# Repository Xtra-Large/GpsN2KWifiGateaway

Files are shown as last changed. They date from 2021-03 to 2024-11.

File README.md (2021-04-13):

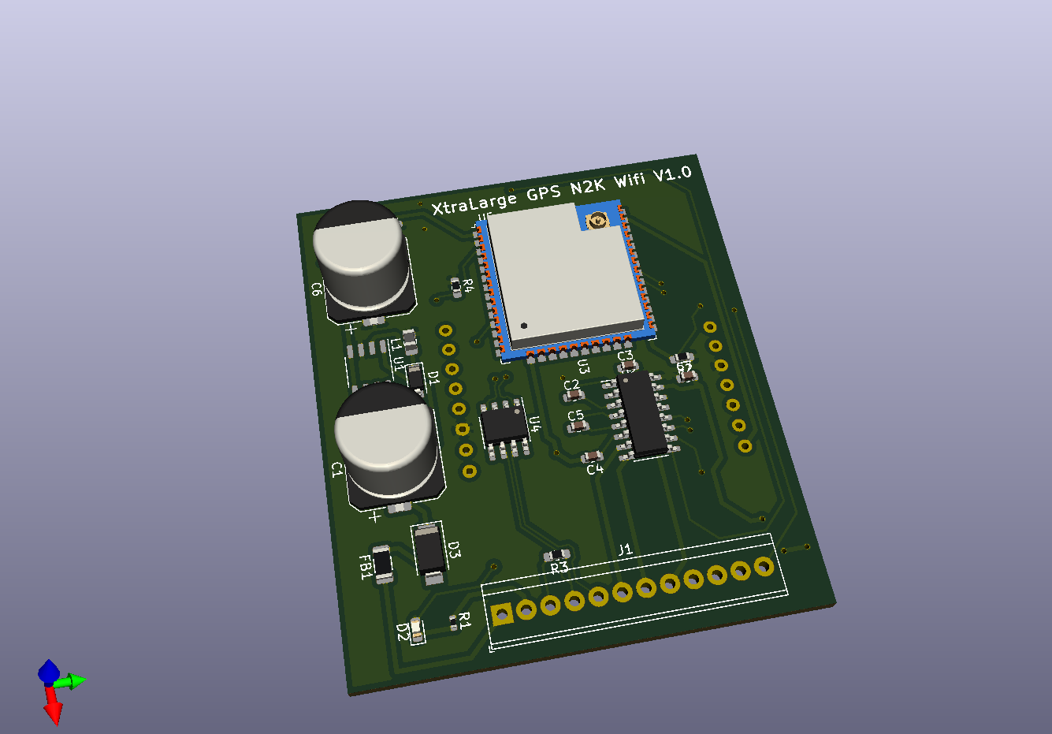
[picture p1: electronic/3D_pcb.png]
Vue 3D


# GpsN2KWifiGateaway

Ce projet est encore en développement, n'hésitez pas à participer!

## Présentation

L'objectif initial de ce projet etait de disposer d'un GPS NMEA 2000 ayant une fréquence de rafraichissement d'au moins 10Hz pour l'intégrer dans notre Archambault A31 (https://epsilon3dsailingteam.fr/).

Il semble que les pilotes automatiques intègrent les données GPS pour effectuer des corrections de trajectoire.

Les GPS Ublox M8N (assez peu couteux) permettent, apèrs configuration, d'obtenir ces taux de rafraichissement en étant mono constellation.
Le nouveelles puces M9N permettent d'obtenir un taux de rafraichissement de 25Hz en exploitant les 4 constellations (GPS, Glonass, Galiléo et Baidoo).

## Projet

Le projet est constitué : 
- Une partie électronique constituée :
  - D'une puce ESP 32 
  - D'un puce GPS M9N, dans la première version nous utilisons une carte Sparkfun (https://www.sparkfun.com/products/15712)
- Un boitier à imprimer en 3D (en cours)
- Le code source du projet

Le code source peut être ouvert avec l'IDE Arduino et le projet électronique avec kiCAD

## Librairies externes utilisées

Le code source utilise ces librairies, sous licence MIT elles aussi :
- Plusieurs librairies de, https://github.com/ttlappalainen : NMEA0183, NMEA2000, NMEA2000_esp32
- https://github.com/ronzeiller/NMEA0183-AIS
- https://github.com/sparkfun/SparkFun_u-blox_GNSS_Arduino_Library

## Fonctions implémentées

Actuellement le projet permet :
- D'injecter sur le réseau NMEA2000 les données de la puce GPS a la fréquence de 20Hz (25Hz possible, a voir l'intérêt)
- Se connecter à un réseau Wifi existant
- Creer un point d'accès Wifi
- Lire les données du réseau NMEA2000, les convertir en MNEA0183 et les router vers :
-- 3 ports série 
-- Wifi en TCP et en UDP

## RoadMap
- Page Web de configuration visualisation
  - Ajout du serveur de configuration Wifi pour configuration sur un routeur externe
  - Ajout de fonction AJAX/JSON pour rechargement de la page de statut
  - Mise en une seule page pour intégrer la fonction de MAJ du firmware
  - Ajout d'option pour activer certaines redirections vers les ports et le reseau (a stocker en NVS)
  - Mise en page et logo
  - Configuration des ports de sortie serie : Msg NMEA, vitesse, activation...
  - Configuration du SSID externe + PWD

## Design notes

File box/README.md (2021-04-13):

# GpsN2KWifiGateaway Box

Ce projet est encore en développement, n'hésitez pas à participer!

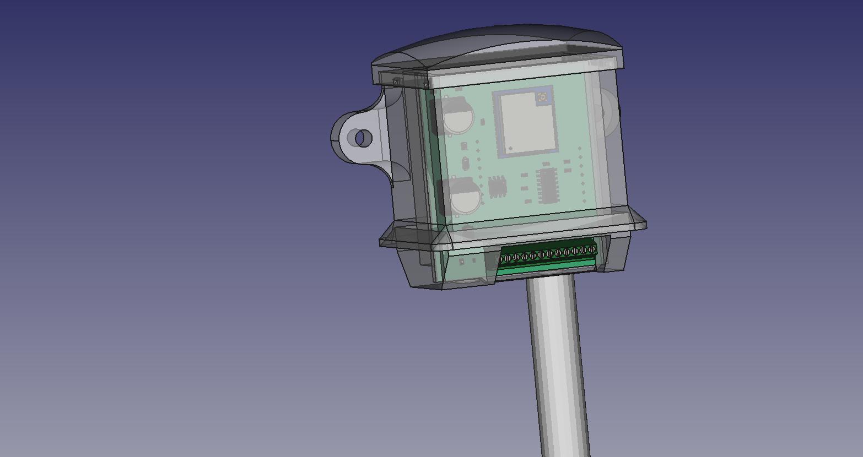
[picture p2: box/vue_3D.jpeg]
Vue 3D


Ce boitier permet l'intégration et la fixation du GPS dans le bateau.

Il n'est pas étanche, mais il est conçu de telle manière que l'eau ne rentre pas dedans, et que la condensation puisse s'évacuer.

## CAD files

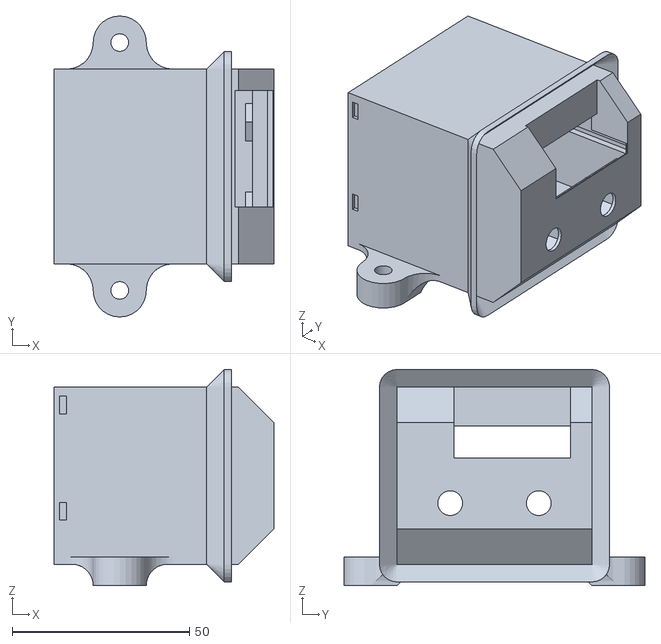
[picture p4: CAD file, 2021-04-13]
box/Boitier (Meshed).stl
62.0 x 85.0 x 61.0

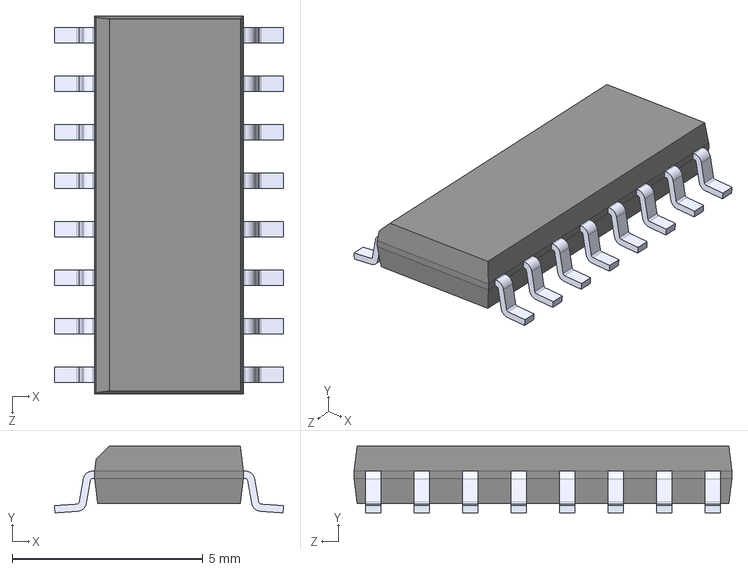
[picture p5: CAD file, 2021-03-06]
electronic/Composants/MAX3232CDR.step
6.00 x 1.75 x 9.90 mm

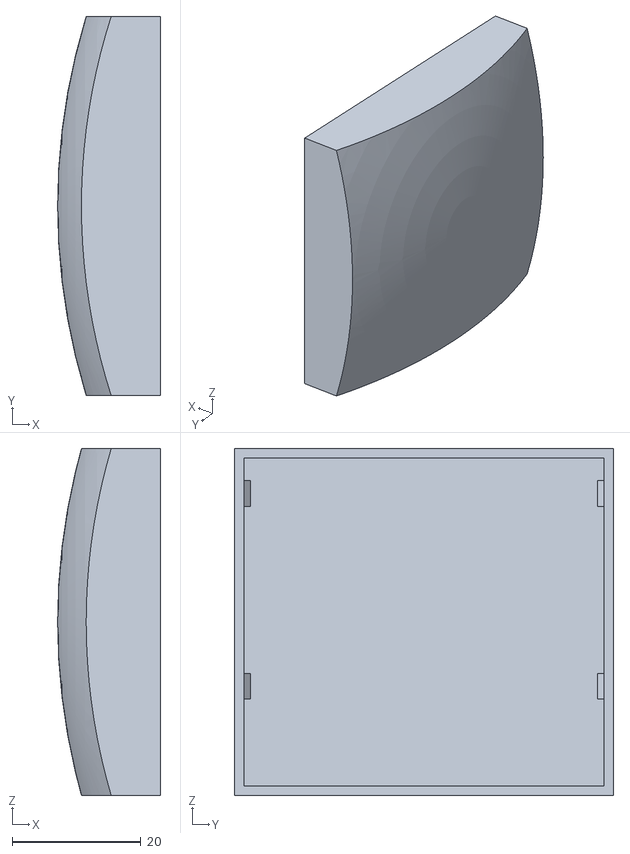
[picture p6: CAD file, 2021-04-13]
box/Couvercle (Meshed).stl
16.0 x 59.0 x 54.0

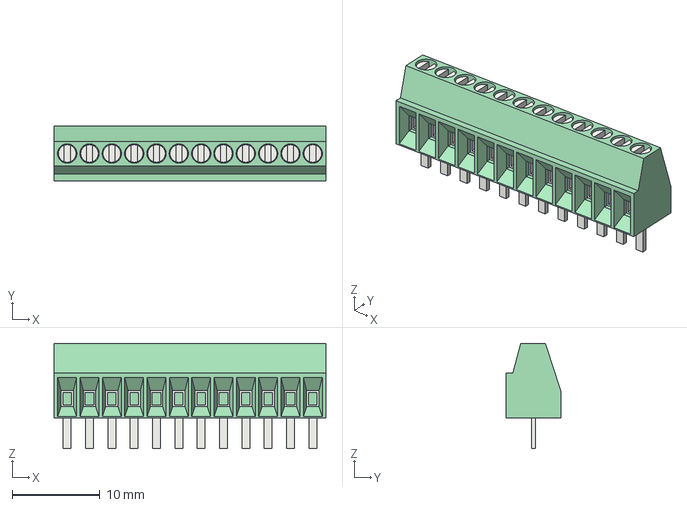
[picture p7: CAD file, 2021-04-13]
box/TerminalBlock_Phoenix_MPT-0,5-12-2.54_1x12_P2.54mm_Horizontal.step
30.9 x 6.20 x 12.0 mm

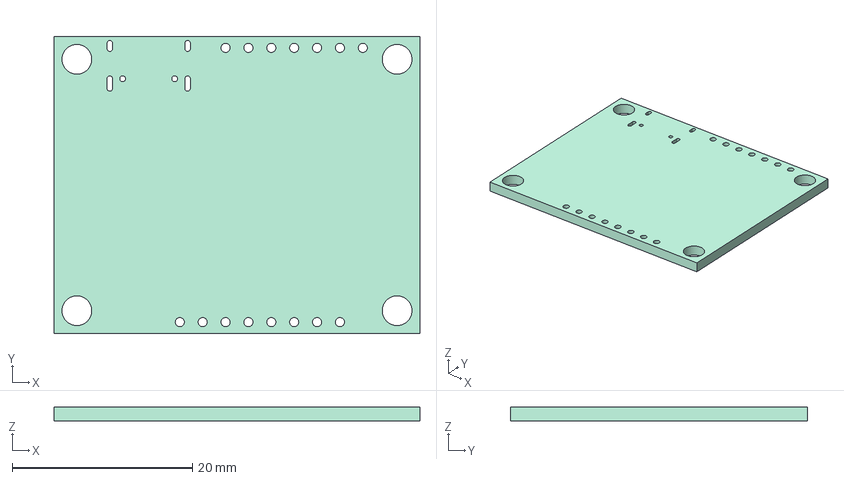
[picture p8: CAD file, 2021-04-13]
box/SparkFun GPS NEO_M9N_uFL1-SparkFun GPS NEO_M9N_uFL.step
40.6 x 33.0 x 1.60 mm

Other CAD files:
box/boitier.FCStd

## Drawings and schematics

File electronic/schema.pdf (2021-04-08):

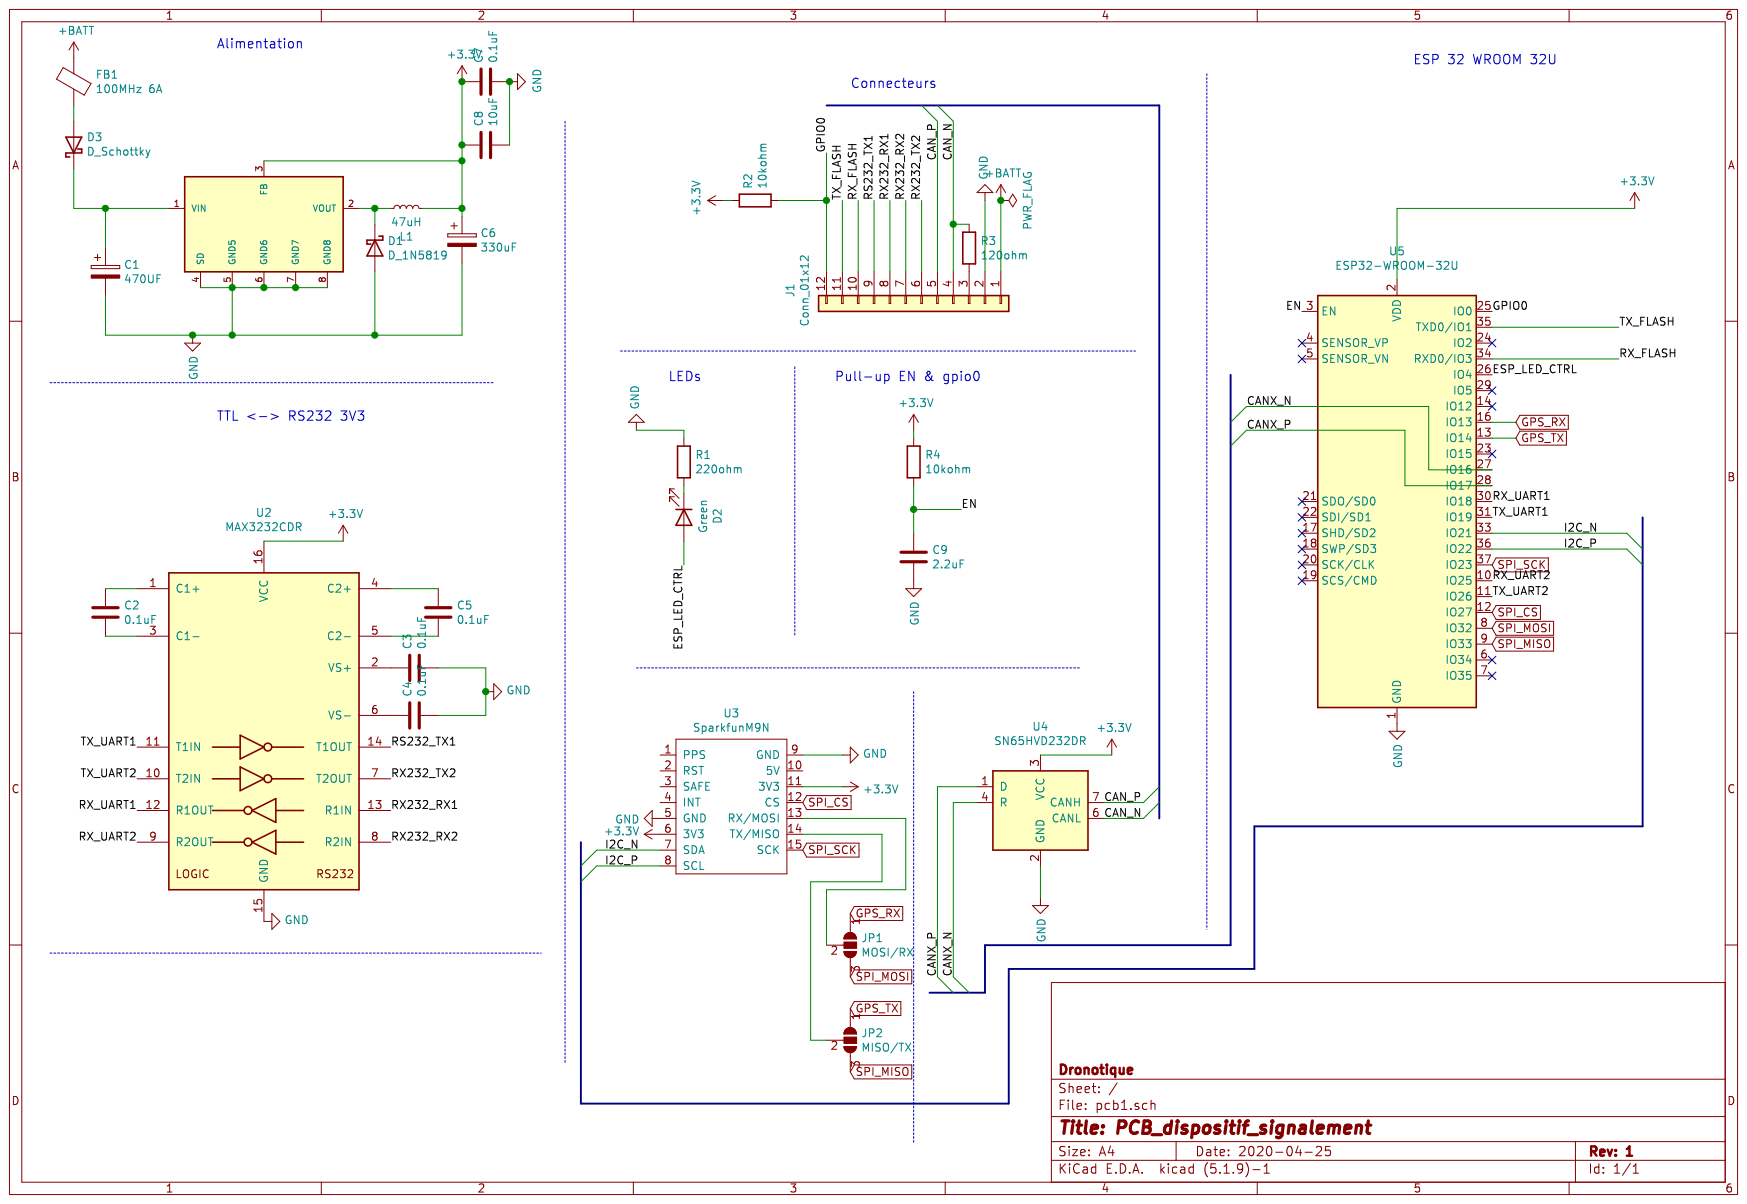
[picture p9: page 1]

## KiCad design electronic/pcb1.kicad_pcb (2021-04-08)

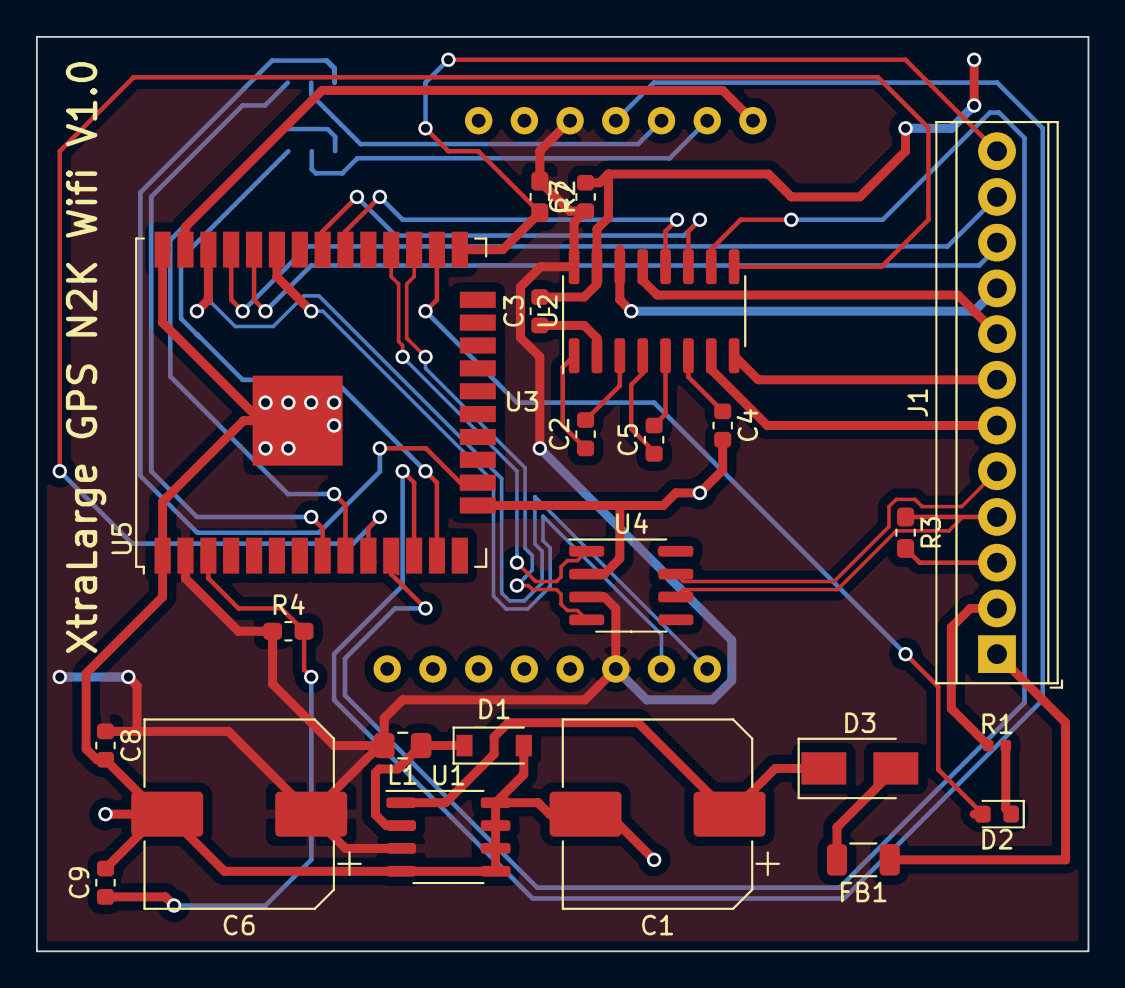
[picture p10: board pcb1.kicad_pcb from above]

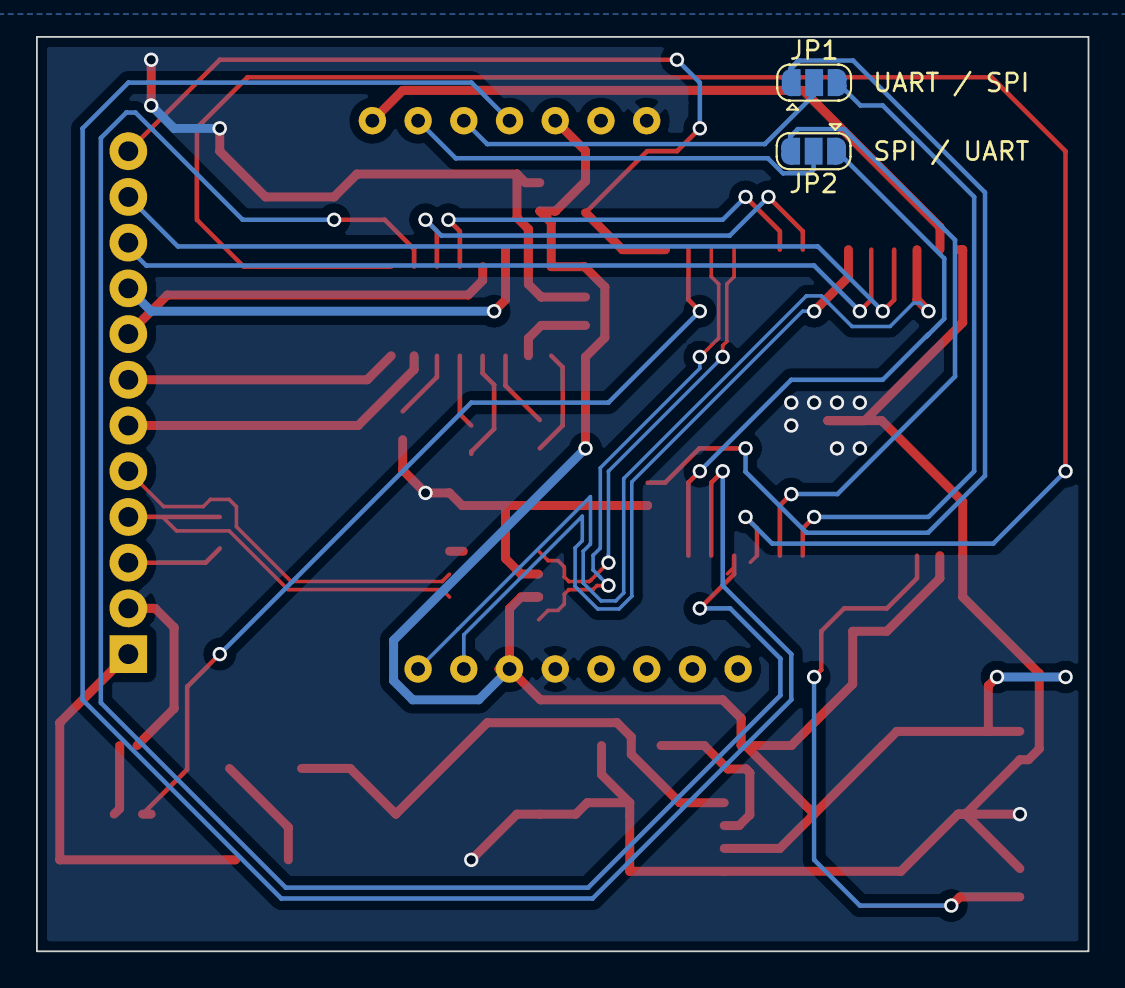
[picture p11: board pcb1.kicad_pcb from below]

Board: 2 copper layers, 58.4 x 50.8 mm, 26 parts (2 on the bottom side), 41 nets.

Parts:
C1: 470UF; CP_Elec_10x10
C2, C3, C4, C5, C7: 0.1uF; C_0603_1608Metric
C6: 330uF; CP_Elec_10x10
C8: 10uF; C_0603_1608Metric
C9: 2.2uF; C_0603_1608Metric
D1: D_1N5819; D_SOD-123
D2: Green; LED_0603_1608Metric
D3: D_Schottky; D_SMA
FB1: 100MHz 6A; R_1206_3216Metric
J1: Conn_01x12; TerminalBlock_TE_1-282834-2_1x12_P2.54mm_Horizontal
JP1: MOSI/RX; SolderJumper-3_P1.3mm_Open_RoundedPad1.0x1.5mm
JP2: MISO/TX; SolderJumper-3_P1.3mm_Open_RoundedPad1.0x1.5mm
L1: 47uH; L_0805_2012Metric_Pad1.15x1.40mm_HandSolder
R1: 220ohm; R_0402_1005Metric
R2, R4: 10kohm; R_0603_1608Metric_Pad1.05x0.95mm_HandSolder
R3: 120ohm; R_0603_1608Metric_Pad1.05x0.95mm_HandSolder
U1: XLSEMI XL1509-3.3E1; SOP-8_3.9x4.9mm_P1.27mm
U2: MAX3232CDR; SOIC-16_3.9x9.9mm_P1.27mm
U3: SparkfunM9N; AdafruitGPSM9N
U4: SN65HVD232DR; SOIC-8_3.9x4.9mm_P1.27mm
U5: ESP32-WROOM-32U

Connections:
+3V3: C6.1, C7.1, C8.1, L1.2, R2.1, R4.1, U1.3, U2.16, U3.6, U3.11, U4.3, U5.2
+BATT: FB1.1, J1.1
/CANX_N: U4.4, U5.27
/CANX_P: U4.1, U5.28
/CAN_N: J1.4, R3.1, U4.6
/CAN_P: J1.5, U4.7
/EN: C9.1, R4.2, U5.3
/ESP_LED_CTRL: D2.2, U5.26
/GPIO0: J1.12, R2.2, U5.25
/I2C_N: U3.7, U5.33
/I2C_P: U3.8, U5.36
/RS232_TX1: J1.9, U2.14
/RX232_RX1: J1.8, U2.13
/RX232_RX2: J1.7, U2.8
/RX232_TX2: J1.6, U2.7
/RX_FLASH: J1.10, U5.34
/RX_UART1: U2.12, U5.30
/RX_UART2: U2.9, U5.10
/TX_FLASH: J1.11, U5.35
/TX_UART1: U2.11, U5.31
/TX_UART2: U2.10, U5.11
GND: C1.2, C3.2, C4.2, C6.2, C7.2, C8.2, C9.2, D1.2, J1.2, R1.1, U1.4, U1.5, U1.6, U1.7, U1.8, U2.15, U3.5, U3.9, U4.2, U5.1, U5.15, U5.38, U5.39
GPS_RX: JP1.1, U5.16
GPS_TX: JP2.1, U5.13
unnamed: C1.1, D3.1, U1.1
unnamed: C2.1, U2.1
unnamed: C2.2, U2.3
unnamed: C3.1, U2.2
unnamed: C4.1, U2.6
unnamed: C5.1, U2.4
unnamed: C5.2, U2.5
unnamed: D1.1, L1.1, U1.2
unnamed: D2.1, R1.2
unnamed: D3.2, FB1.2
unnamed: J1.3, R3.2
unnamed: JP1.2, U3.13
unnamed: JP2.2, U3.14
SPI_CS: U3.12, U5.12
SPI_MISO: JP2.3, U5.9
SPI_MOSI: JP1.3, U5.8
SPI_SCK: U3.15, U5.37

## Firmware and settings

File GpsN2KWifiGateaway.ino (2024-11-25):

/*
Copyright (c) 2021-2025 Aurelien TRICAULT - XtraLarge
Permission is hereby granted, free of charge, to any person obtaining a copy of
this software and associated documentation files (the "Software"), to deal in
the Software without restriction, including without limitation the rights to use,
copy, modify, merge, publish, distribute, sublicense, and/or sell copies of the
Software, and to permit persons to whom the Software is furnished to do so,
subject to the following conditions:
The above copyright notice and this permission notice shall be included in all
copies or substantial portions of the Software.
THE SOFTWARE IS PROVIDED "AS IS", WITHOUT WARRANTY OF ANY KIND, EXPRESS OR IMPLIED,
INCLUDING BUT NOT LIMITED TO THE WARRANTIES OF MERCHANTABILITY, FITNESS FOR A
PARTICULAR PURPOSE AND NONINFRINGEMENT. IN NO EVENT SHALL THE AUTHORS OR COPYRIGHT
HOLDERS BE LIABLE FOR ANY CLAIM, DAMAGES OR OTHER LIABILITY, WHETHER IN AN ACTION OF
CONTRACT, TORT OR OTHERWISE, ARISING FROM, OUT OF OR IN CONNECTION WITH THE SOFTWARE
OR THE USE OR OTHER DEALINGS IN THE SOFTWARE.
*/


/**Ce programme utilise les librairies suivantes :
 * https://github.com/ttlappalainen/NMEA0183
 * https://github.com/ttlappalainen/NMEA2000
 * https://github.com/ttlappalainen/NMEA2000_esp32
 * https://github.com/ronzeiller/NMEA0183-AIS
 * https://github.com/sparkfun/SparkFun_u-blox_GNSS_Arduino_Library
 * 
 * 
 * Il faut aussi installer manuellement la librairie BlinkControl, celle fournie par les IDE Arduino n'etant plus MAJ
 * https://github.com/Xtra-Large/BlinkControl
 * 
 */

/**
 * TODO
 *  - Ajout UDP sur IP locale?
 *  - Ajout du serveur de configuration Wifi pour configuration sur un routeur externe
 *  - TCP NMEA2K (voir si intéret)
 *  - UDP NMEA2K (voir si intéret)
 *  - Ajout de fonction AJAX/JSON pour rechargement de la page de statut
 *    -> Mise en une seule page pour intégrer la fonction de MAJ du firmware
 *    -> Ajout d'option pour activer certaines redirections vers les ports et le reseau (a stocker en NVS)
 *    -> Mise en page et logo
 *    -> Configuration des ports de sortie serie : Msg NMEA, vitesse, activation...
 *    -> Configuration du SSID externe + PWD
 *  - TCP Broadcast NMEA2K (voir si intéret)
 *  - TCP Broadcast NMEA0183
 *  
 *  20210213 
 *    - ADD HOSTNAME + services DNS
 *    - Sortie NMEA0183 sur les 3 ports serie (pour ajout éventuel d'un pilote sur ce port)
 *    - Ajout port serie 2
 *    - UDP NMEA0183 broadcast
 *    - TCP NMEA1083

 *  20241125
 *    - MAJ des librairies pour compilation
 */


#pragma once
/*
  * Module de conversion GPS Ublox (M8N) vers NMEA 2000 à 10Hz
  * Copyright Dronotique - Aurélien TRICAULT
 */

extern "C" {
#include "esp_wifi.h"
#include "driver/uart.h"
}
 
#define DEBUG_ON false

#define VERSION 0.12
#define VERSION_STR "0.12"
#include <cstdint>
#include <Arduino.h>
#include <WiFi.h>
#include <WebServer.h>
#include <BlinkControl.h>
//OTA
#include <WiFiClient.h>
#include <ESPmDNS.h>
#include <Update.h>

//Manipulation des dates/times
#include <TimeLib.h>

//Stockage de l'adresse sur le bus N2K
#include <Preferences.h>
int NodeAddress;  // To store last Node Address
Preferences preferences;             // Nonvolatile storage on ESP32 - To store LastDeviceAddress
bool updateEnCours = false;

#include "configuration.h"

#include <Wire.h> //Needed for I2C to GPS


//gestion des pins
#define RX2_PIN GPIO_NUM_25
#define TX2_PIN GPIO_NUM_26
//#define RX1_PIN GPIO_NUM_9 //Non utilisable
//#define TX1_PIN GPIO_NUM_10 //Non utilisable
#define RX1_PIN GPIO_NUM_18
#define TX1_PIN GPIO_NUM_19
#define RX0_PIN GPIO_NUM_3
#define TX0_PIN GPIO_NUM_1
#define I2C_SDA GPIO_NUM_21
#define I2C_SCL GPIO_NUM_22
//#define ESP32_CAN_TX_PIN GPIO_NUM_16
//#define ESP32_CAN_RX_PIN GPIO_NUM_4
//#define ESP32_CAN_TX_PIN GPIO_NUM_5
//#define ESP32_CAN_RX_PIN GPIO_NUM_4
#define ESP32_CAN_TX_PIN GPIO_NUM_17
#define ESP32_CAN_RX_PIN GPIO_NUM_16
#define SPI_SCK GPIO_NUM_23
#define SPI_CS GPIO_NUM_27
#define SPI_MOSI GPIO_NUM_32
#define SPI_MISO GPIO_NUM_33

//#include <HardwareSerial.h>
//HardwareSerial MySerial1(1);
#define GNSS_ON_SERIAL false
#define DEFAULT_BAUD_RATE 115200
#define BAUD_RATE_SIZE 5
int baudsRates[] = {38400, 115200, 9600, 57600, 4800};



//GPS
//#include <SparkFun_Ublox_Arduino_Library.h>
#include <SparkFun_u-blox_GNSS_Arduino_Library.h>
#define NUM_SAT_MIN 5
#define GPS_HDOP_MIN 2.5
#define defaultMaxWait 10000 //Max wait for GPS Ublox ... Augmenter car bug sinon
SFE_UBLOX_GNSS myGNSS;
#define MAX_GPS_FREQUENCY 25

//NMEA 2000
#define N2K_FRAME_BUFFER_SIZE 250
#define N2K_FRAME_RECEIVE_BUFFER_SIZE 100


//#define NMEA2000_FRAME_ERROR_DEBUG
//#define NMEA2000_FRAME_IN_DEBUG
//#define NMEA2000_FRAME_OUT_DEBUG
//#define NMEA2000_MSG_DEBUG
//#define NMEA2000_BUF_DEBUG
//#define NMEA2000_DEBUG

#include <NMEA2000_CAN.h>
#include <N2kMessages.h>

// List here messages your device will transmit.
// Set the information for other bus devices, which messages we support
const unsigned long TransmitMessages[] PROGMEM = {129029L,129026L,129025L,0};
const unsigned long ReceiveMessages[] PROGMEM = {/*126992L,*/ // System time
      127250L, // Heading
      127258L, // Magnetic variation
      128259UL,// Boat speed
      128267UL,// Depth
      129025UL,// Position
      129026L, // COG and SOG
      129029L, // GNSS
      129025L, // LAT + LON RAPID
      130306L, // Wind
      128275UL,// Log
      127245UL,// Rudder
      129038L, //AIS Classe A
      129039L, //AIS Classe B
      12979UL, //AIS Classe A static
      129809L, //AIS Classe B static
      129810L, //AIS Classe B static
      0
    };

#define RapidDataUpdatePeriod 50 //20Hz //In millisec - Some strange periot to cause Slow and rapid to run unsync.
#define SlowDataUpdatePeriod 500 //2Hz //In millisec - Some strange periot to cause Slow and rapid to run unsync.
#define MiscDataUpdatePeriod 5000 //0.2Hz //In millisec - Some strange periot to cause Slow and rapid to run unsync.
unsigned long RapidDataUpdated=0;
unsigned long SlowDataUpdated=0;
unsigned long MiscDataUpdated=0;

//COnversion en NMEA0183
#include "N2kDataToNMEA0183.h"
#include "List.h"
#include "BoardSerialNumber.h"
#include "BoatData.h"
#include <WiFiUdp.h>
#define SEND_SEA_SMART true
#if SEND_SEA_SMART 
  #include "Seasmart.h"
#endif

using namespace std;

//Gestion de la led
/*4 mode pour la led
 * Eteinte = Module non alimenté
 * Fixe = Initialisation en cours
 * Clignotement lent = Acquisition GPS en cours
 * Clignotement rapide = Module prêt
 */
#define PIN_LED 12 //16
BlinkControl led(PIN_LED);
int blinkState = 0; //0 = ON, 1 = 1hZ, 2=3hz

//GPS 
#define NUM_SAT_MIN 5 //Nombre de satelitte mini pour considérer la position comme valide
#define GPS_HDOP_MIN 4 //HDOP mini pour considérer la position comme valide
#define HZ_TO_READ_GPS 10 //Frequence de la lecture de la position GPS
long lastTimeReadGPS; //Dernière lectuer du GPS

bool gpsInitialized = false;

long n2kMsgId = 0;

tBoatData boatData;
bool gpsPositionUpdated = false;
bool gpsCogSogUpdated = false;

bool initiatlisationCompleted = false;

//SSID et PWD
#define HOSTNAME "GPS20HZN2K"
#define WIFI_SSID "GPS20HZN2K"
#define WIFI_PWD "xtralarge"
#define WIFI_CHANNEL 6
String mySsid;
String myPwd;

//Connexion au Wifi du bateau => TODO Passer les valeur en NVS et les rendre editable via l'interface Web
const char *wifi_network_ssid = "XXXXXXXXXXXXXXXX";
const char *wifi_network_password = "XXXXXXXXXXXXXXXXXXXXXXX";

//Server Web OTA et webApp
// Set web server port number to 80
#define WEBSERVER_PORT 80
WebServer server(WEBSERVER_PORT);

//Web Server NMEA0183 TCP et UDP
tN2kDataToNMEA0183 tN2kDataToNMEA0183(&NMEA2000, 0);
#define MAX_TCP_CLIENT_NMEA0183 10
#define WIFISERVER_NMEA0183_PORT 2947
#define UDP_NMEA0183_PORT 2948
WiFiServer serverNMEA0183(WIFISERVER_NMEA0183_PORT, MAX_TCP_CLIENT_NMEA0183); //10 clients max
using tWiFiClientPtr = std::shared_ptr<WiFiClient>;
LinkedList<tWiFiClientPtr> clientsNMEA0183;
WiFiUDP udpNmea0183;

#define MAX_TCP_CLIENT_NMEA2K 10
#define WIFISERVER_NMEA2K_PORT 2948
#define UDP_NMEA2K_PORT 2948
WiFiServer serverNMEA2K(WIFISERVER_NMEA0183_PORT, MAX_TCP_CLIENT_NMEA0183); //10 clients max
using tWiFiClientPtr = std::shared_ptr<WiFiClient>;
LinkedList<tWiFiClientPtr> clientsNMEAN2K;
//WiFiUDP udpNmea2K;

IPAddress broadCastIPAddress;
IPAddress broadCastIPAddressStation;

#define TIME_DEBUG_ALIVE  300000 //Au bout de 5 minutes on eteind toutes les fonctionnalités de debug (Serial1 et Wifi + OTA)
String gpsCnxMode = "AUCUN GPS";

int printLogs(const char *fmt, va_list args) {
  Serial.print(fmt);
}

void setup() {
  esp_log_set_vprintf(printLogs);
  
  Serial.begin(DEFAULT_BAUD_RATE);
  //Serial1.begin(DEFAULT_BAUD_RATE, SERIAL_8N1, RX1_PIN, TX1_PIN, true, 11000UL);  // Passing 0 for baudrate to detect it, the last parameter is a timeout in ms
  Serial1.begin(DEFAULT_BAUD_RATE, SERIAL_8N1, RX1_PIN, TX1_PIN);
  Serial2.begin(DEFAULT_BAUD_RATE, SERIAL_8N1, RX2_PIN, TX2_PIN);
  //Serial1.begin(DEFAULT_BAUD_RATE);
  Serial.println("////////////////////////////////////////////////////////");
  Serial.print("GPS 20 Hz NMEA 2000/0183 - Version : ");
  Serial.print(VERSION);
  uint32_t id = GetBoardSerialNumber();
  Serial.print(" SN : ");
  Serial.println(id);                               
  Serial.println("////////////////////////////////////////////////////////");
  
  led.begin();
  led.on();

  //COnfiguration du reseau et serveur WIFI
  mySsid = String(WIFI_SSID); 
  char ssid_c[mySsid.length()];
  mySsid.toCharArray(ssid_c, mySsid.length());
  WiFi.config(INADDR_NONE, INADDR_NONE, INADDR_NONE, INADDR_NONE);
  WiFi.setHostname(HOSTNAME);
  WiFi.mode(WIFI_MODE_APSTA);
  WiFi.softAP(ssid_c, WIFI_PWD, WIFI_CHANNEL, false, 4);
  //Connexion au routeur Wifi
  WiFi.begin(wifi_network_ssid, wifi_network_password);

  broadCastIPAddressStation = WiFi.localIP(); // find my local IP address
  broadCastIPAddress = WiFi.softAPIP();
  broadCastIPAddressStation[3] = 255;
  broadCastIPAddress[3] = 255;         // Set last octet to 255 for Class C broadcast address of this subnet

  String ipAdrrAP = String(broadCastIPAddress[0]) + "." + String(broadCastIPAddress[1]) + "." + String(broadCastIPAddress[2]) + "." + String(broadCastIPAddress[3]);
  String ipAdrrStation = String(broadCastIPAddressStation[0]) + "." + String(broadCastIPAddressStation[1]) + "." + String(broadCastIPAddressStation[2]) + "." + String(broadCastIPAddressStation[3]);
  MDNS.begin(HOSTNAME);
  MDNS.addService("_nmea","_udp",UDP_NMEA0183_PORT);
  MDNS.addServiceTxt("_nmea","_udp","Host",HOSTNAME);
  MDNS.addServiceTxt("_nmea","_udp","IP", ipAdrrAP);
  MDNS.addService("_nmea","_tcp",UDP_NMEA0183_PORT);
  MDNS.addServiceTxt("_nmea","_tcp","Host",HOSTNAME);
  MDNS.addServiceTxt("_nmea","_tcp","IP", ipAdrrAP);
   
  configureWebServer();

#if DEBUG_ON
  Serial.print("UDP Adresse : ");
  Serial.print(broadCastIPAddress[0]);
  Serial.print(".");
  Serial.print(broadCastIPAddress[1]);
  Serial.print(".");
  Serial.print(broadCastIPAddress[2]);
  Serial.print(".");
  Serial.println(broadCastIPAddress[3]);
#endif
  vTaskDelay(1000/portTICK_PERIOD_MS);
#if DEBUG_ON
    myGNSS.enableDebugging(Serial, false);
#endif

  //Trying UART
  //Connexion au GPS par le port serie
  //Serial.begin(baudsRates[0], SERIAL_8N1, -1, -1);
#if GNSS_ON_SERIAL   
  int i=0;
  for(i; i < BAUD_RATE_SIZE; i++){
#if DEBUG_ON
    Serial.print("Trying on UART port with baudrate : ");
    Serial.println(baudsRates[i]);
#endif
    Serial1.updateBaudRate(baudsRates[i]);
    vTaskDelay(100/portTICK_PERIOD_MS);
    
    gpsInitialized = myGNSS.begin(Serial1);
    if (gpsInitialized){
      break;
    }
    //A t'on trouvé 
    if (gpsInitialized){
      gpsCnxMode = "UART";
#if DEBUG_ON
      Serial.print("GPS initialisé a une vitesse de ");
      Serial.print(baudsRates[i]);
      Serial.println(" BAUD");
#endif
      delay(100);
      if(i != 0){ //On n'est pas sur la vitesse par defaut, on change ca
#if DEBUG_ON
        Serial.print("Changement du BAUD rate pour ");
        Serial.println(baudsRates[0]);
#endif
        //myGNSS.setSerial1Rate(baudsRates[0]);
        delay(100);
      }
    }else{
      Serial.println("Aucun GPS trouvé sur le port UART");
    }
  }
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
void loop() {
  if(updateEnCours){
    vTaskDelay(10000/portTICK_PERIOD_MS);
  }
  //Reception des trames NMEA2000 et envoi NMEA0183
  CheckConnectionsNMEA0183();
  //Taches de gestions globales
  server.handleClient();
  led.loop();

  if (isPositionValide()) {
      //Position GPS valide 
    if(blinkState != 2){
      led.blink3();
      blinkState = 2;
    } 
  }else{
    //Attente position GPS
    if(blinkState != 1){
      led.blink1();  
      blinkState = 1;
    }  
  }
  vTaskDelay(10/portTICK_PERIOD_MS);
}



//###################################################################################
//Serveur Web
//###################################################################################
void configureWebServer(){
  server.on("/", home_page);
  server.on("/update", update_page);
  
  /*handling uploading firmware file */
  server.on("/update_go", HTTP_POST, update_go_page, update_HandleFirware);
  server.begin();
}

void home_page(){
  
  String homePage = WEB_HOME_PAGE;
  homePage.replace("[VERSION]", String(VERSION));
  homePage.replace("[ID_DISPOSITIF]", String(GetBoardSerialNumber()));
  homePage.replace("[PROTOCOLE_MODE]", gpsCnxMode);
  
  if(gpsInitialized){
    //homePage.replace("[FIX_GPS]", (_droneSignal.isPositionFixed() ? "OUI" : "En attente"));
    homePage.replace("[NB_SAT]", String(boatData.nbSat));
    //homePage.replace("[HDOP]", String(_droneSignal.getGpsHdop()));
    //String curLat = DD_DDDDDtoDDMMSS(abs(_droneSignal.getLat())/100000.0);
    String curLat = String(abs((double)boatData.Latitude/10000000.0));
    curLat.replace("°", "&deg;");
    homePage.replace("[LAT]", (boatData.Latitude>=0 ? "N" : "S") + curLat);
    //String curLng = DD_DDDDDtoDDMMSS(abs(_droneSignal.getLon())/100000.0);
    String curLng = String(abs((double)boatData.Longitude/10000000.0));
    curLng.replace("°", "&deg;");
    homePage.replace("[LON]", (boatData.Longitude>=0 ? "E" : "O") + curLng);
    homePage.replace("[Alt]", String((double) ((double)boatData.Altitude/1000.0f)));
    homePage.replace("[SPEED]", String((double) ((double)boatData.SOG/1000.0)));
    homePage.replace("[ROUTE]", String((double) (((double)boatData.COG/100000.0)* M_PI /180.0)));
  }else{
    homePage.replace("[FIX_GPS]", "GPS Non initialisé");
  }

  server.send(200, "text/html", homePage); 
}

void update_page(){
  server.send(200, "text/html", WEB_UPDATE_PAGE); 
}

void update_go_page(){
  server.sendHeader("Connection", "close");
  server.send(200, "text/plain", (Update.hasError()) ? "FAIL" : "OK");
  ESP.restart();
}

void update_HandleFirware(){
  HTTPUpload& upload = server.upload();
  if (upload.status == UPLOAD_FILE_START) {
    Serial.printf("Update: %s\n", upload.filename.c_str());
    updateEnCours = true;
    if (!Update.begin(UPDATE_SIZE_UNKNOWN)) { //start with max available size
      updateEnCours = false;
      Update.printError(Serial1);
    }
  } else if (upload.status == UPLOAD_FILE_WRITE) {
    /* flashing firmware to ESP*/
    if (Update.write(upload.buf, upload.currentSize) != upload.currentSize) {
      updateEnCours = false;
      Update.printError(Serial1);
    }
  } else if (upload.status == UPLOAD_FILE_END) {
    if (Update.end(true)) { //true to set the size to the current progress
      Serial.printf("Update Success: %u\nRebooting...\n", upload.totalSize);
    } else {
      updateEnCours = false;
      Update.printError(Serial1);
    }
  }
}


//###################################################################################
//GPS
//###################################################################################

bool isPositionValide(){
  //return ( _droneSignal.isPositionFixed() && _droneSignal.getSatNumber() >= NUM_SAT_MIN && _droneSignal.getGpsHdop() <= GPS_HDOP_MIN);
  return true;
}

String DD_DDDDDtoDDMMSS( double DD_DDDDD)
{    
 int DD=(int)DD_DDDDD;
 int MM=(int)((DD_DDDDD - DD)*60);
 int SS=(int)((DD_DDDDD - DD)*60-MM)*60;
 return String(DD) + "°" + String(MM) + "'" + String(SS);
}

//###################################################################################
//NMEA2000
//###################################################################################
bool IsTimeToUpdate(unsigned long NextUpdate) {
  return (NextUpdate<millis());
}

unsigned long InitNextUpdate(unsigned long Period, unsigned long Offset=0) {
  return millis()+Period+Offset;
}

unsigned long InitNextUpdate(unsigned long Period) {
  return InitNextUpdate(Period, 0);
}

void SetNextUpdate(unsigned long &NextUpdate, unsigned long Period) {
  while ( NextUpdate<millis() ) NextUpdate+=Period;
}


//###################################################################################
//SEASMART
//###################################################################################
#define MAX_NMEA2000_MESSAGE_SEASMART_SIZE 500
#define MAX_NMEA2000_MESSAGE_SIZE 82
//*****************************************************************************
//NMEA 2000 message handler
void HandleNMEA2000Msg(const tN2kMsg &N2kMsg) {
  char buf[MAX_NMEA2000_MESSAGE_SEASMART_SIZE];
#if SEND_SEA_SMART
    if (N2kToSeasmart(N2kMsg, millis(), buf, MAX_NMEA2000_MESSAGE_SEASMART_SIZE) == 0 ){  
      SendBufToClients(buf);
    }
#endif

//TODO send UDP and TCP N2K message 
  /*char bufN2k[MAX_NMEA2000_MESSAGE_SIZE]; 
  int n2kMsgLenght = 0;
  N2kMsg.GetBuf(bufN2k, MAX_NMEA2000_MESSAGE_SIZE, n2kMsgLenght);
  Serial.println("Sending UDP NMEA2K message");
  udpNmea2K.beginPacket(broadCastIPAddress, UDP_NMEA2K_PORT);  // Send to UDP
  udpNmea2K.write((byte*)bufN2k, MAX_NMEA2000_MESSAGE_SIZE);
  udpNmea2K.endPacket();*/


}

#define MAX_NMEA0183_MESSAGE_SIZE 82
//NMEA 0183 sentences vary in length, but each sentence is limited to 79 characters or
//less. This length limit excludes the $ and the [CR][LF] characters. The data field block,
//including delimiters is limited to 74 characters or less.
//*****************************************************************************
void SendNMEA0183Message(const tNMEA0183Msg &NMEA0183Msg) {
  //Sending to TCP client
  char buf[MAX_NMEA0183_MESSAGE_SIZE];
  if (NMEA0183Msg.GetMessage(buf, MAX_NMEA0183_MESSAGE_SIZE) ) {
    //TCP
    SendBufToClients(buf);
    //Sending to UDP
#if DEBUG_ON
    Serial.println("Sending UDP NMEA0183 message");
#endif
    udpNmea0183.beginPacket(broadCastIPAddress, UDP_NMEA0183_PORT);  // Send to UDP
    udpNmea0183.write((uint8_t*)buf, MAX_NMEA0183_MESSAGE_SIZE);
    udpNmea0183.endPacket();

    udpNmea0183.beginPacket(broadCastIPAddressStation, UDP_NMEA0183_PORT);  // Send to UDP
    udpNmea0183.write((uint8_t*)buf, MAX_NMEA0183_MESSAGE_SIZE);
    udpNmea0183.endPacket();
    

    //Serial
    Serial.println(buf);
    Serial1.println(buf);
    Serial2.println(buf);
  }
}

//***********************  WEBSERVER  *****************************************
// NMEA0183 Sätze an alle Clients senden
void SendBufToClients(const char *buf) {
  for (auto it=clientsNMEA0183.begin() ;it!=clientsNMEA0183.end(); it++) {
    if ( (*it)!=NULL && (*it)->connected() ) {
      (*it)->println(buf);
    }
  }
}

//*****************************************************************************
void AddClient(WiFiClient &client) {
#if DEBUG_ON
  Serial.println("New Client.");
#endif
  clientsNMEA0183.push_back(tWiFiClientPtr(new WiFiClient(client)));
}

//*****************************************************************************
void StopClient(LinkedList<tWiFiClientPtr>::iterator &it) {
#if DEBUG_ON
  Serial.println("Client Disconnected.");
#endif
  (*it)->stop();
  it = clientsNMEA0183.erase(it);
}

//*****************************************************************************
void CheckConnectionsNMEA0183() {
  WiFiClient client = serverNMEA0183.available();   // listen for incoming clients

  if ( client ) AddClient(client);

  for (auto it = clientsNMEA0183.begin(); it != clientsNMEA0183.end(); it++) {
    if ( (*it) != NULL ) {
      if ( !(*it)->connected() ) {
        StopClient(it);
      } else {
        if ( (*it)->available() ) {
          char c = (*it)->read();
          if ( c == 0x03 ) StopClient(it); // Close connection by ctrl-c
        }
      }
    } else {
      it = clientsNMEA0183.erase(it); // Should have been erased by StopClient
    }
  }
}

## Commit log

2021-04-08 1ere version partie en prodcution
    Modification sur les pin de l'ESP32 utilisés,
    Modification de quelques composants
    ajout de toutes les références
2021-04-08 Ajout de la vue 3D
2021-04-13 Version 1.0 proto commande JLCPCB
    [pcb1.sch]
2021-04-13 Intégration du dome du couvercle dans le couvercle
    [Boitier (Meshed).stl, Couvercle (Meshed).stl, Dome couvercle (Meshed).stl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]
2024-11-25 Update BoardSerialNumber.cpp
    MAJ des librairies
2024-11-25 Update GpsN2KWifiGateaway.ino
    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
2024-11-25 Update N2kDataToNMEA0183.cpp
    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
2024-11-25 Update GpsN2KWifiGateaway.ino
    Ajout d'un commentaire sur la librairie Blink Control

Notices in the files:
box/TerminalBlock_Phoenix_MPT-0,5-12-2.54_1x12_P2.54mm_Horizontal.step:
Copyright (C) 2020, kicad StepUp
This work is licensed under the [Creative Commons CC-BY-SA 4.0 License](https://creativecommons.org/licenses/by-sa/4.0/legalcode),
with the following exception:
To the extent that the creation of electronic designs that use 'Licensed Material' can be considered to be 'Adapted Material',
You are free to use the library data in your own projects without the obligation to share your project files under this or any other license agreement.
